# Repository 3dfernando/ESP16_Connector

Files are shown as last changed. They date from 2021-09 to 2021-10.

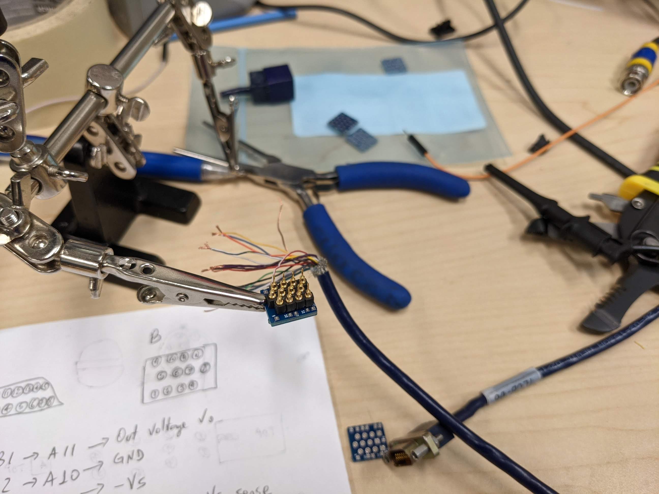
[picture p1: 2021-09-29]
Pictures/Assembly 1.jpg

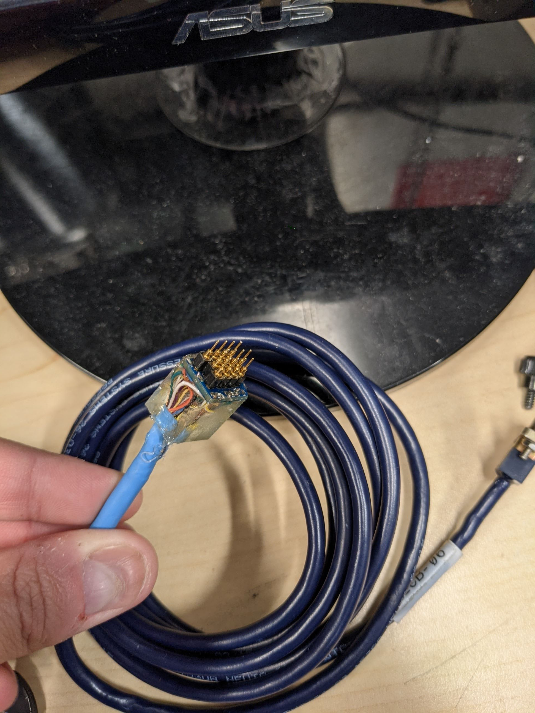
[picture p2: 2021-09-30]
Pictures/PXL_20210929_192932988.jpg

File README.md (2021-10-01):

# ESP16_Connector
Simple connector for the ESP-16 pressure transducer. The custom connector (12-pin) continually broke accidentally because its pins are exposed and very fragile. This is a fix for it. I'm assuming the Miniature DB-15 side of the cable is intact (usually true because that side is well-protected by a shell.)

BOM to fix this connector is very simple:
Just get 3x 4-pin header connectors with 0.018" (0.45mm) diameter pins. NORMAL HEADER CONNECTORS HAVE 0.75mm diameter pins. DON'T USE THOSE AS THEY DON'T FIT!!

Here's the connector I used:
https://www.digikey.com/en/products/detail/mill-max-manufacturing-corp/342-10-104-00-591000/4455942

Solder the headers according to the connection diagram inside the Pictures folder.

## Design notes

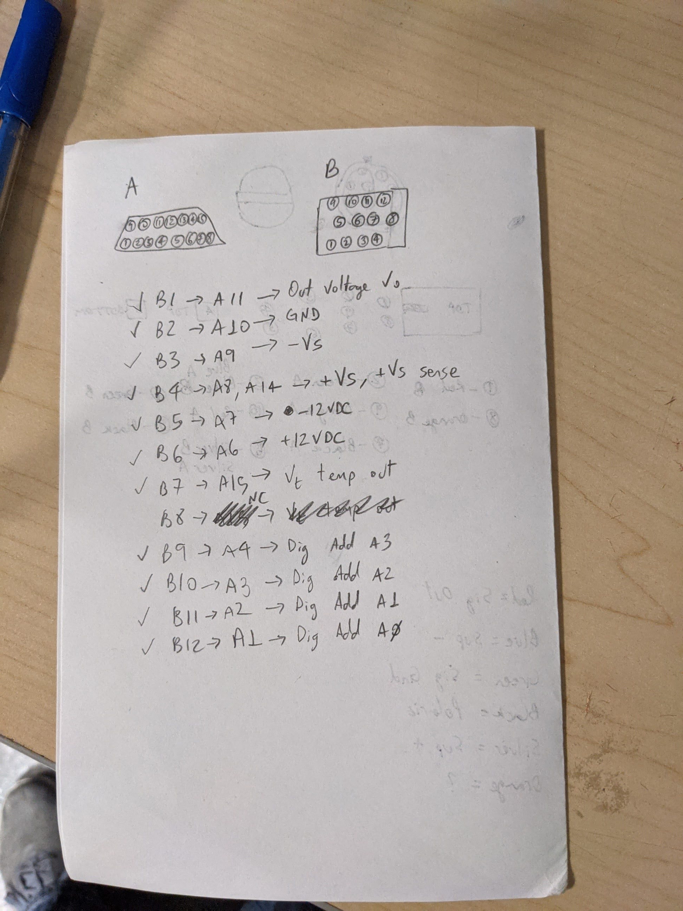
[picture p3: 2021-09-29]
Pictures/Connection Diagram.jpg

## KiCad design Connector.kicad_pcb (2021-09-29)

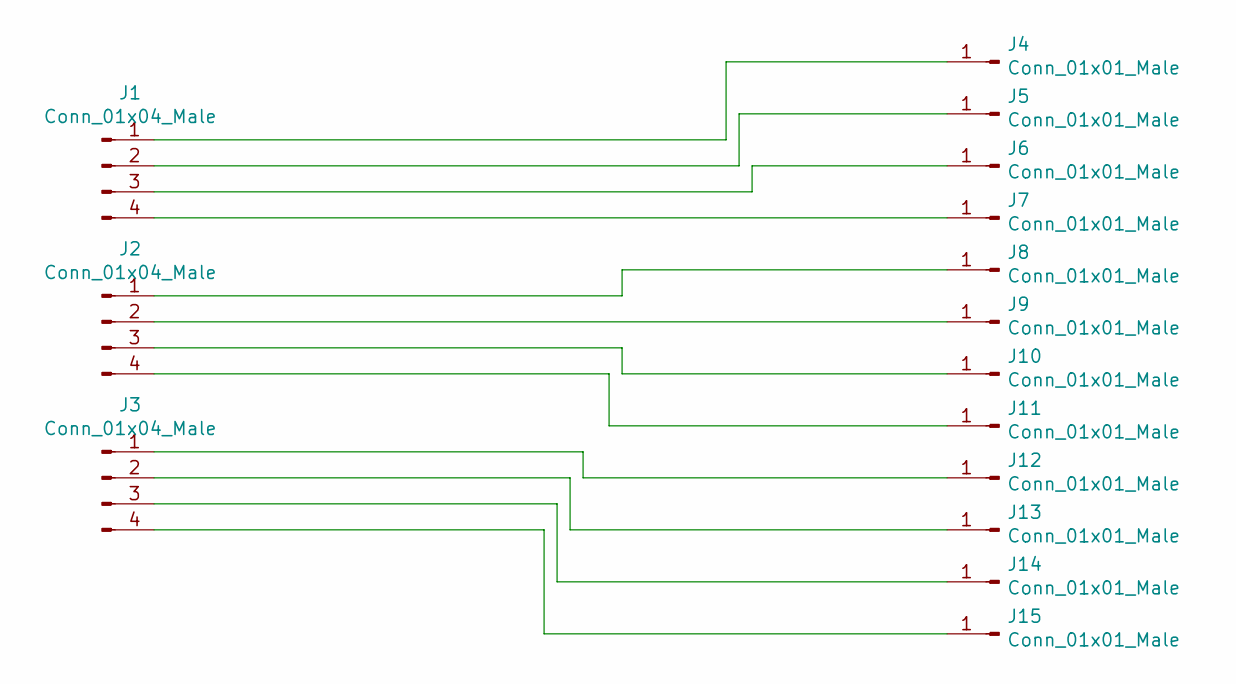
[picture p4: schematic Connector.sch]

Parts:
J1, J2, J3: Conn_01x04_Male; PinHeader_1x04_P2.54mm_Vertical
J4, J5, J6, J7, J8, J9, J10, J11, J12, J13, J14, J15: Conn_01x01_Male; PinHeader_1x01_P1.27mm_Vertical

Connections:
unnamed: J1.1, J4.1
unnamed: J1.2, J5.1
unnamed: J1.3, J6.1
unnamed: J1.4, J7.1
unnamed: J2.1, J8.1
unnamed: J2.2, J9.1
unnamed: J2.3, J10.1
unnamed: J2.4, J11.1
unnamed: J3.1, J12.1
unnamed: J3.2, J13.1
unnamed: J3.3, J14.1
unnamed: J3.4, J15.1

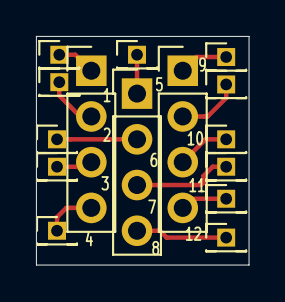
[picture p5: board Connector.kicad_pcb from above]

Board: 2 copper layers, 11.8 x 12.7 mm, 15 parts (0 on the bottom side), 12 nets.
